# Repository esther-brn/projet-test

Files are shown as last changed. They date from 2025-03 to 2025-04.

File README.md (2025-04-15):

# 4GP 2024/2025 - Projet de capteur *low-tech en graphite* - Par Esther BOIRON et Margot HERNANDEZ
-------------------------

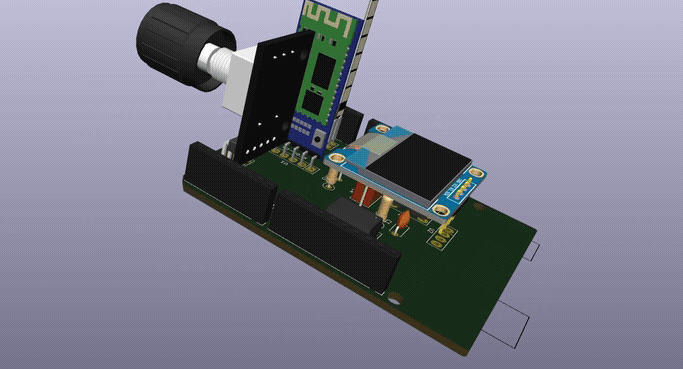
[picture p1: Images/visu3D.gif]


## Table des matières
* [Contacts](#contacts) 
* [Contexte](#contexte) 
* [Livrable](#livrable) 
* [Matériel requis](#matériel-requis) <br>
* [1. Simulation électronique sous LTSpice](#1-simulation-électronique-sous-ltspice) <br>
* [2. Design du PCB sous Kicad](#2-design-du-pcb-sous-kicad) <br>
* [3. Code sur Arduino](#3-code-sur-arduino) <br>
* [4. Application Android](#4-application-android) <br>
* [5. Réalisation du shield](#5-réalisation-du-shield) <br>
* [6. Banc de tests](#6-banc-de-tests) <br>
* [7. Résultats et discussion](#7-résultats-et-discussion) <br>
* [8. Datasheet du capteur](#8-datasheet-du-capteur) 
* [Conclusion](#conclusion)
------------
## Contacts
Esther BOIRON : eboiron@insa-toulouse.fr  
Margot HERNANDEZ : mhernan2@insa-toulouse.fr

------------
## Contexte
Dans le cadre de l’UF de quatrième année du département Génie Physique intitulée *Du capteur au banc de test*, nous avons développé et évalué la performance d’un capteur low-tech en graphite. Il est constitué d’un simple morceau de papier recouvert d’une trace de crayon à papier, formant une fine couche de graphite. Lorsque le papier se déforme, le nombre de particules de graphite reliées varie, entraînant une modification de la résistance du capteur. Ce phénomène permet ainsi de mesurer la déformation, à la manière d’une jauge de contrainte traditionnelle.

Ce travail s’appuie sur les recherches de scientifiques américains (Cheng-Wei Lin*, Zhibo Zhao*, Jaemyung Kim & Jiaxing Huang), qui ont publié en 2014 l’article [Pencil Drawn Strain Gauges and Chemiresistors on Paper](https://www.researchgate.net/publication/259846610_Pencil_Drawn_Strain_Gauges_and_Chemiresistors_on_Paper).

Vous trouverez ici l’ensemble des réalisations effectuées dans le cadre de ce projet : simulations électroniques, conception du PCB, programmation Arduino, développement d’une application Android et élaboration d’une datasheet.

------------
## Livrable
Plusieurs livrables sont attendus :

✓ Un shield PCB connecté à une carte Arduino UNO, intégrant : un capteur en graphite, un montage amplificateur transimpédance, un module Bluetooth, un écran OLED, un encodeur rotatif, un potentiomètre numérique ainsi qu'un capteur de flexion commercial (flex sensor).<br>

✓ Un code Arduino assurant le contrôle de l’ensemble des composants et la réalisation des mesures.<br>

✓ Une application Android permettant de visualiser les mesures depuis un smartphone.<br>

✓ Un code Arduino dédié aux essais du capteur sur le banc de test.<br>

✓ Une datasheet détaillant les caractéristiques du capteur en graphite.<br>

------------
## Matériel requis
Afin de réaliser notre dispositif, voici la liste des composants nécessaires :

Pour le montage amplificateur transimpédance :

* Des résistances : 1 de 1 kΩ, 1 de 10 kΩ, 2 de 100 kΩ
* Un potentiomètre numérique : ici, le MCP41050
* Des condensateurs : trois de 100 nF et un de 1 μF
* Un amplificateur opérationnel : ici, le LTC1050

Pour le reste du dispositif :
* Un module Bluetooth : ici, le HC05
* Un écran OLED : ici, un écran de dimensions 128x64
* Un encodeur rotatif
* Un capteur de flexion (flex sensor)
* Une résistance de 33 kΩ
* Une carte Arduino UNO
------------
## 1. Simulation électronique sous LTSpice
Notre objectif est de mesurer la résistance de notre capteur en graphite puis de retrouver sa déformation par une relation de proportionalité. Nous savons que la résistance est de l’ordre du gigaohm (GΩ). Sous une tension de 5V, correspondant à celle délivrée par l’Arduino, le capteur délivre un courant extrêmement faible, de l’ordre de quelques nanoampères (nA). Cette mesure ne peut donc pas se faire directement : nous devons amplifier le signal. De plus, nous utilisons l'Arduino Uno et ce microcontrôleur ne peut mesurer que des tensions (cf [datasheet](https://docs.arduino.cc/resources/datasheets/A000066-datasheet.pdf)). Nous avons donc besoin d'un montage amplificateur transimpédance pour convertir notre courant en une tension exploitable par les entrées analogiques de l'Arduino. Pour cela, nous avons choisi l’amplificateur opérationnel  LTC1050.

Associé à cet amplificateur, nous réalisons un montage structuré en trois zones principales qui correspondent à des filtres pour améliorer la qualité du signal mesuré :

* Filtrage en entrée de l'amplificateur (R1 et C1) : un filtre passe-bas passif de fréquence de coupure de 16 Hz qui permet de filtrer le bruit en courant sur le signal d'entrée
* Filtrage couplé à l'amplificateur (R3 et C4) : un filtre passe-bas actif de fréquence de coupure de 1.6 Hz qui permet de filtrer la composante 50 Hz issue du réseau électrique 
* Filtrage à la sortie de l'amplificateur (R6 et C2) : filtre passe bas passif de fréquence de coupure de 1.6 kHz qui permet de réduire le bruit créé lors du traitement du signal (bruits des alimentations, de l’horloge…)

<p align="center">
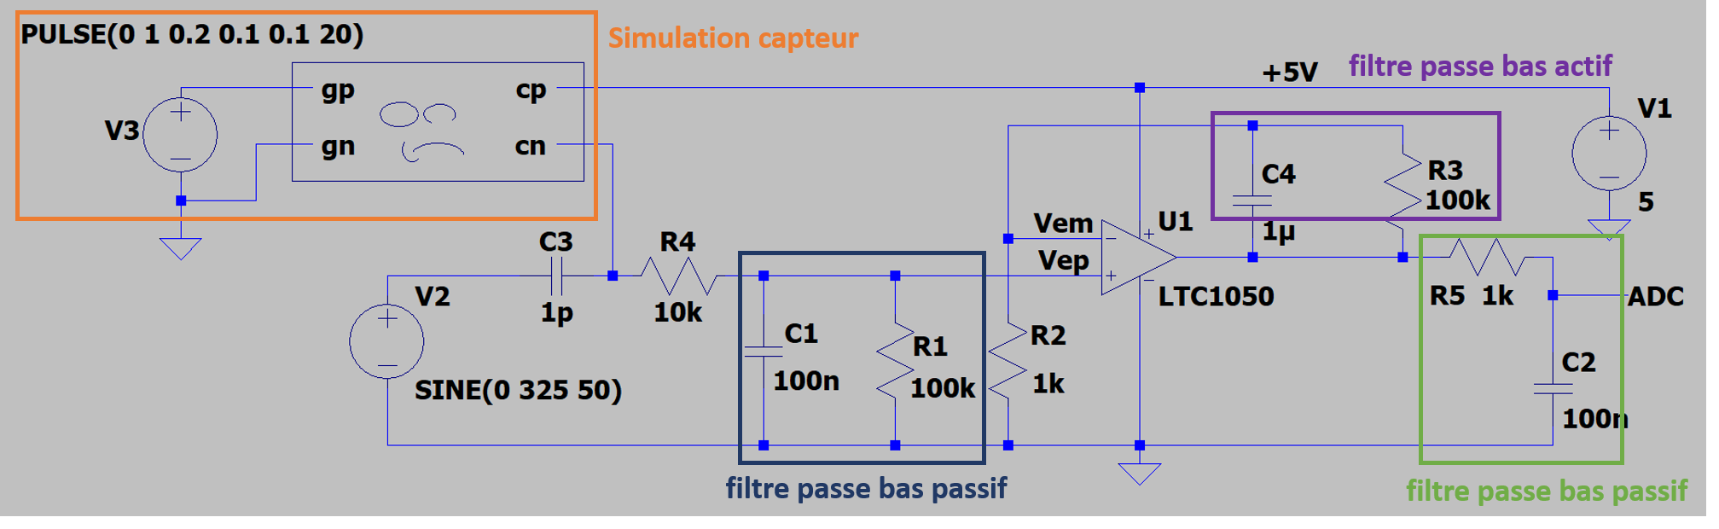
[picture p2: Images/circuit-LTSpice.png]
Image circuit LTSpice
  
</p>

Afin de pouvoir ajuster dynamiquement le gain de l’amplificateur en fonction des besoins de mesure, la résistance R2 sera remplacée ultérieurement par un potentiomètre digital.

Nous avons validé notre montage sur LTSpice en deux étapes :

Tout d'abord, nous avons réalisé une première simulation afin de s’assurer que l’amplification fonctionne correctement. L’image ci-dessous montre que le signal est bien amplifié à 1 V : le signal a donc une valeur suffisante pour être interprété par l’Arduino.

<p align="center">
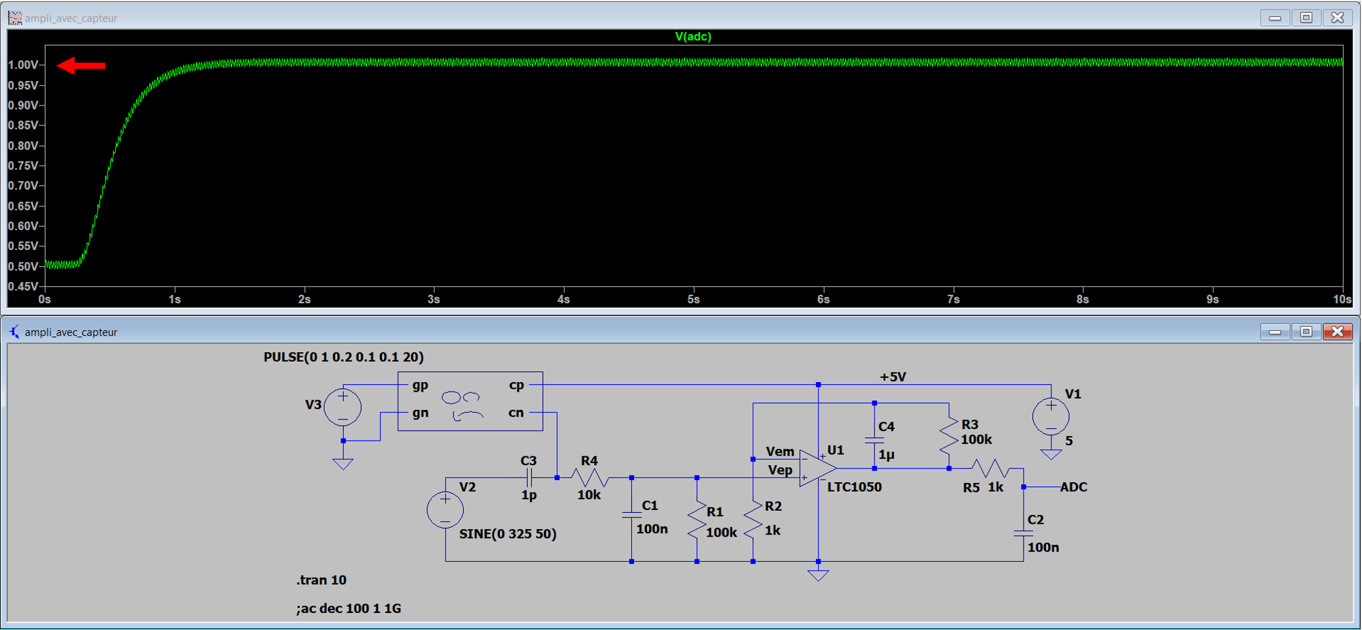
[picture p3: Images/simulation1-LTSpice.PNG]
Image circuit LTSpice
  
</p>

Ensuite, nous avons réalisé une seconde simulation afin d'observer la réponse à un courant alternatif afin de vérifier l’efficacité du filtrage. Les variations de la phase observées sur le graphe ci-dessous illustrent le passage du signal à travers les trois filtres successifs.
<p align="center">
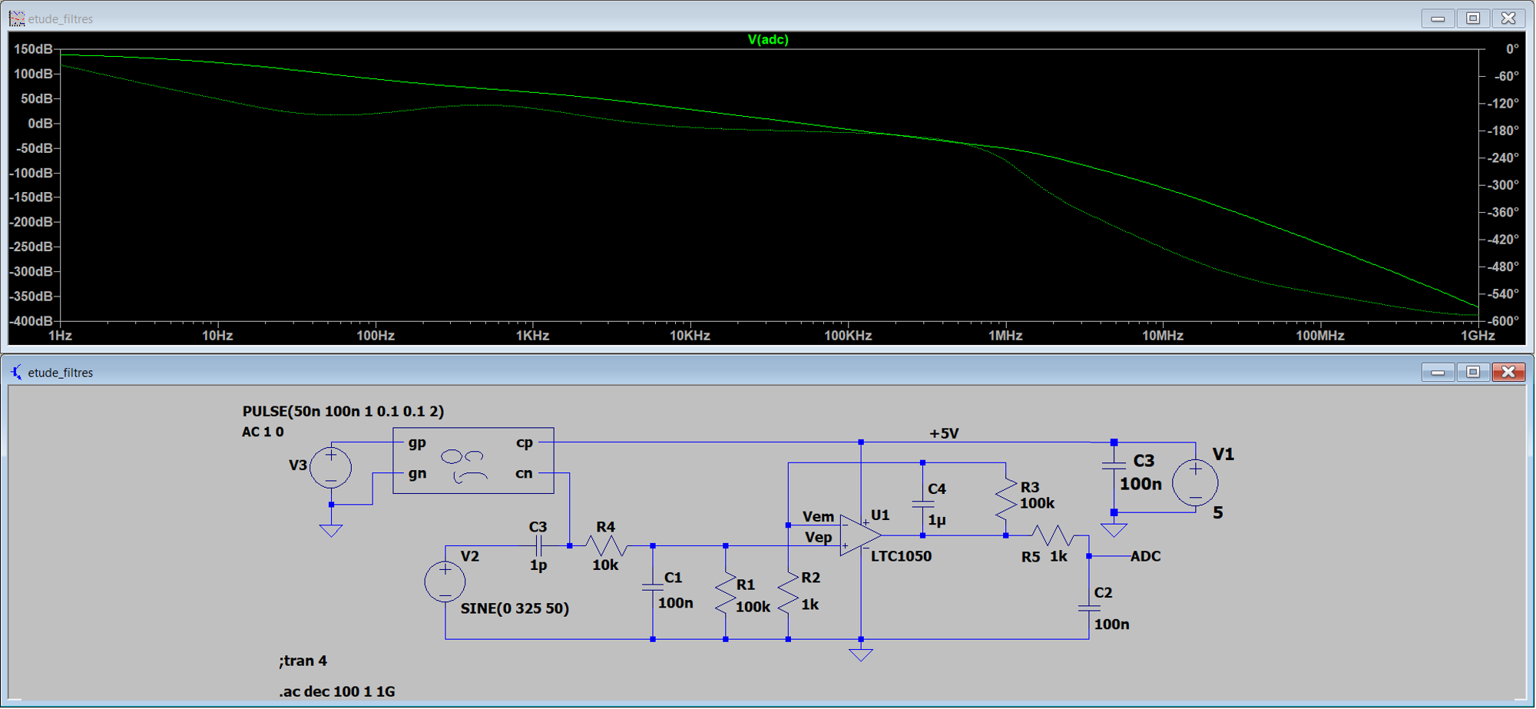
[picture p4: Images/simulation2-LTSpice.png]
Image circuit LTSpice
  
</p>

------------
## 2. Design du PCB sous Kicad
Après avoir réalisé les simulations sur LTSpice, nous avons conçu notre PCB à l’aide du logiciel KiCad. Pour cela, nous sommes parties du schéma du montage décrit précédemment, auquel nous avons apporté quelques modifications.
Parmi ces modifications, nous avons notamment remplacé la résistance R2 par un potentiomètre numérique permettant un réglage précis du gain de l’amplificateur, tout en évitant la saturation. Nous avons également ajouté plusieurs composants afin d’améliorer les fonctionnalités de notre système et de comparer les résultats obtenus :
* Le module Bluetooth HC-05 : permet d'assurer la communication entre le PCB et un smartphone via une application Android.
* Un écran OLED : utilisé pour afficher différents menus en temps réel.
* Un encodeur rotatif : contrôle la navigation entre les différentes options affichées sur l’écran OLED.
* Un flex sensor : utilisé pour comparer les mesures du capteur en graphite avec celles d’un capteur commercial lors des tests finaux

__Création des bibliothèques et symboles__  

La première étape de la conception a consisté à créer notre propre bibliothèque de symboles pour les composants spécifiques du montage. Nous avons dessiné les symboles correspondants aux différents composants utilisés. L’image ci-dessous illustre, par exemple, le symbole de l’écran OLED.

<p align="center">
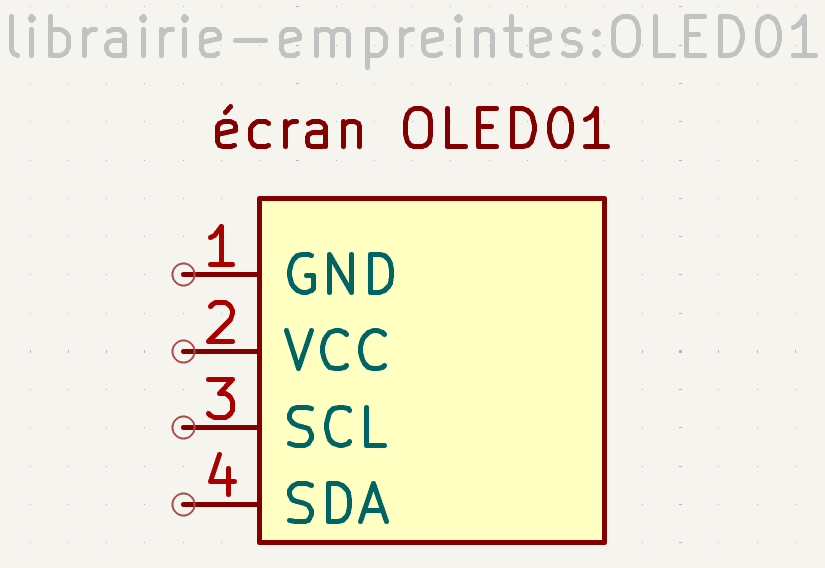
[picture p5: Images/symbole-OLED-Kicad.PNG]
Image circuit LTSpice
  
</p>

__Création des empreintes des composants__

La deuxième étape a consisté à créer les empreintes des composants. Cette phase est essentielle pour garantir une bonne intégration des composants sur le circuit imprimé. Pour cela, nous avons pris en compte la dimension physique des composants ainsi que le diamètre des trous. L’image ci-dessous illustre l’empreinte de l’écran OLED.

<p align="center">
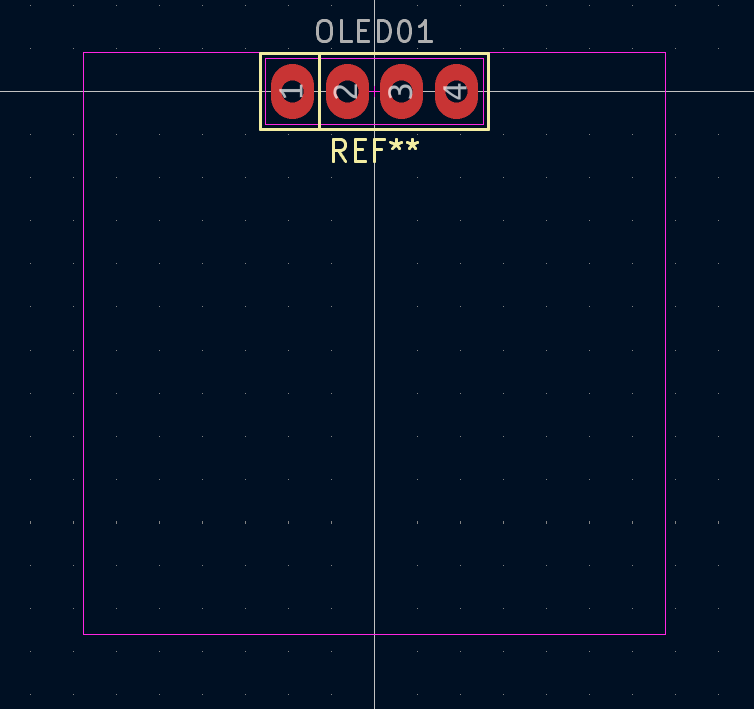
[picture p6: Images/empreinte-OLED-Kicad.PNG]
Image circuit LTSpice
  
</p>

Afin d’obtenir une visualisation 3D réaliste de notre PCB final, nous avons associé à chaque empreinte une modélisation 3D du composant correspondant. Cette étape permet de vérifier l’agencement des composants, d’anticiper d’éventuels problèmes d’encombrement et d’optimiser le design du circuit imprimé.
Les modèles 3D utilisés ont été récupérés sur la plateforme GrabCAD, qui propose une large bibliothèque de fichiers compatibles avec KiCad.
L’image ci-dessous illustre la modélisation 3D de l’écran OLED.

<p align="center">
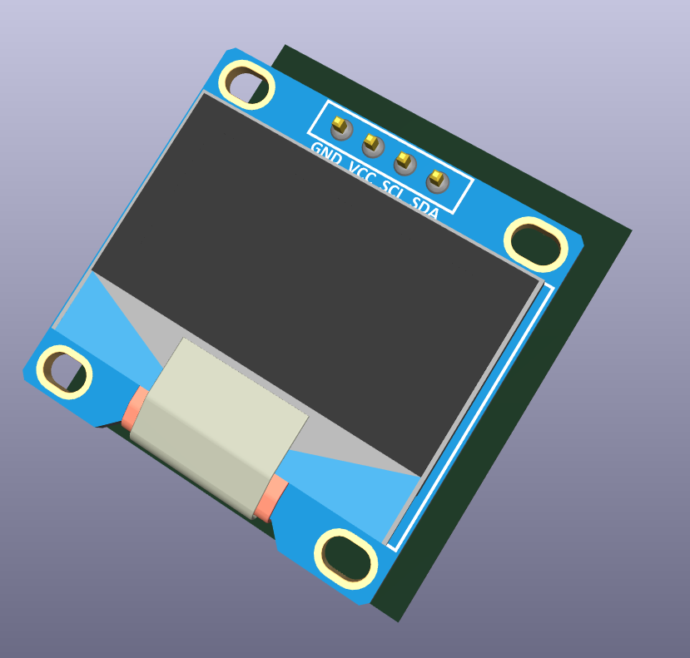
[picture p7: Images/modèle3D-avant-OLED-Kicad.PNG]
Image circuit LTSpice
  
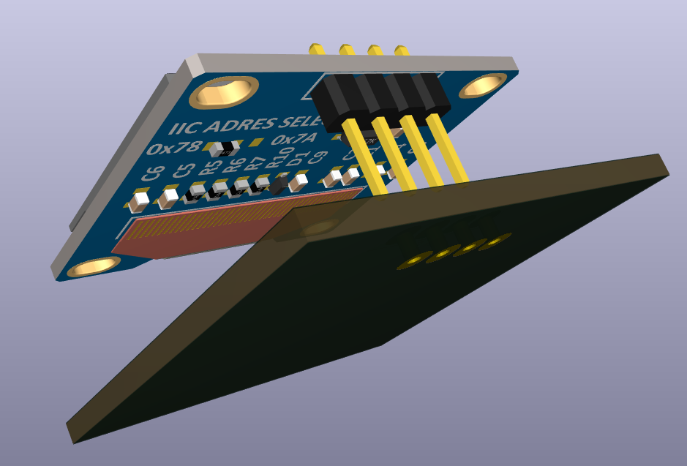
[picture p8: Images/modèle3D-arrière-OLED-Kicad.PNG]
Image circuit LTSpice
  
</p>

__Création de la schématique électrique__

Après avoir défini les empreintes et les modèles 3D des composants, nous avons procédé à la création de la schématique électrique du montage. Lors de cette étape, nous avons opté pour un modèle basé sur l’Arduino UNO afin de garantir la correspondance correcte des pins de connexion avec l’Arduino.

<p align="center">
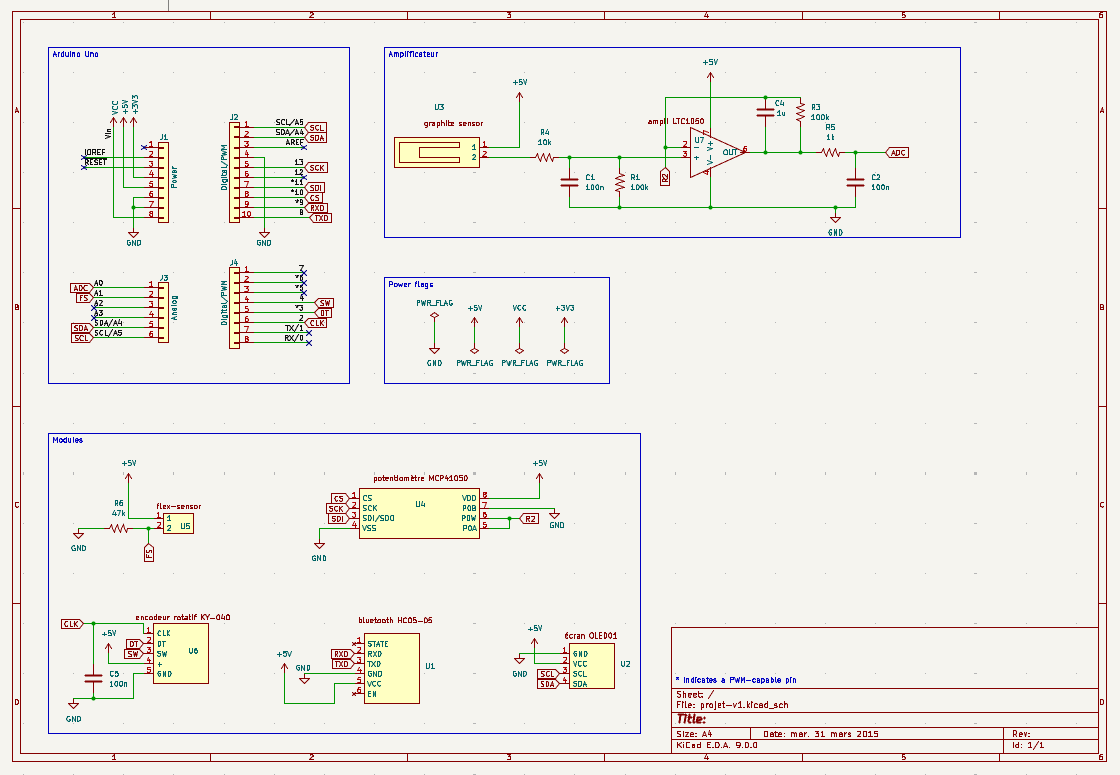
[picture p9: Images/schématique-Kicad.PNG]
Image circuit LTSpice
  
</p>

__Disposition des composants sur le PCB__

La dernière étape de notre conception a été l’agencement des composants sur le PCB. L’objectif principal est d’optimiser leur disposition en tenant compte des connexions électriques tout en minimisant l’utilisation de vias. Les images ci-dessous présentent le résultat final de notre PCB, ainsi que sa vue en 3D, permettant de visualiser l’implantation des composants.

<p align="center">
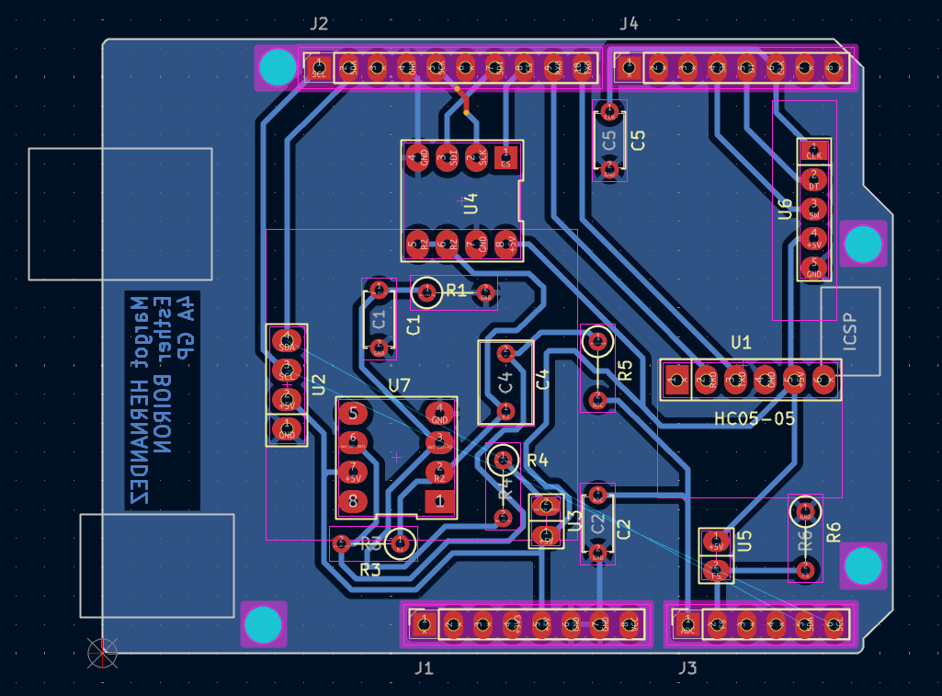
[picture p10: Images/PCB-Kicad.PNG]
Image circuit LTSpice
  
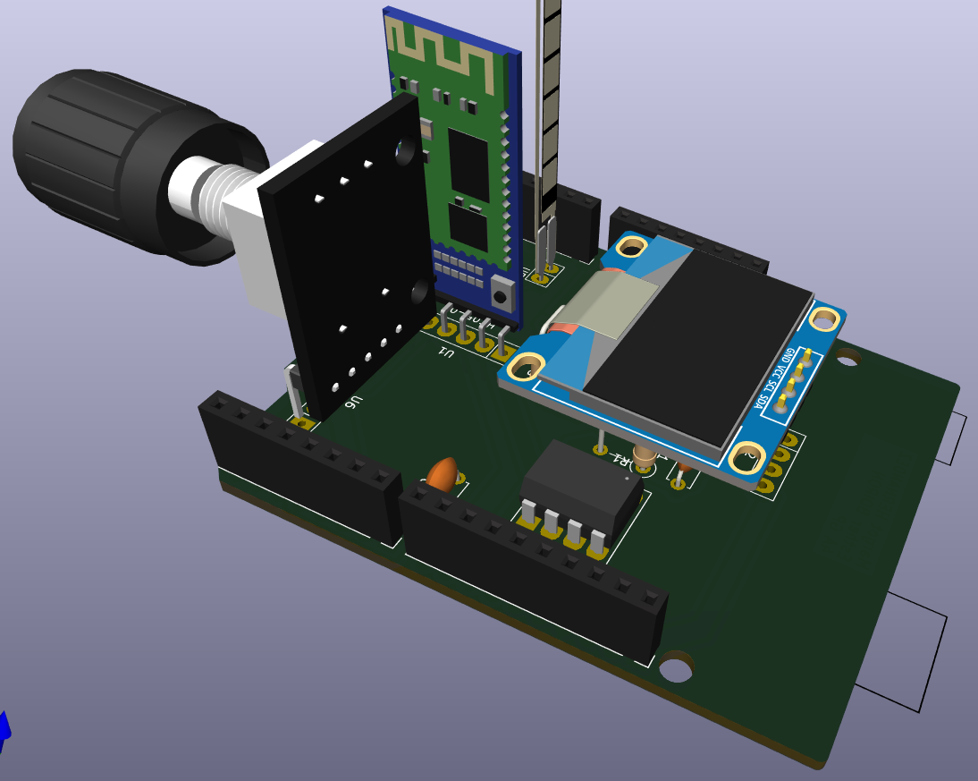
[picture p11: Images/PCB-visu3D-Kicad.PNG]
Image circuit LTSpice
  
</p>

------------
## 3. Code sur Arduino
Notre code Arduino, conçu pour contrôler les composants implémentés et effectuer les mesures à l’aide du capteur en graphite et du capteur commercial, a été développé sous [Arduino IDE 2.3.4](https://www.arduino.cc/en/software/).  

Nous avons utilisé les bibliothèques *SoftwareSerial.h* pour la communication Bluetooth et *Adafruit_SSD1306.h* pour l'affichage sur écran OLED. Étant donné que notre programme utilise une part importante de la mémoire RAM, nous avons rencontré des problèmes de stockage : le programme ne se lançait pas et aucune information n'était affichée dans l'IDE lors du téléversement. Pour remédier à cela, nous avons intégré la bibliothèque *avr/pgmspace.h*, qui permet de stocker des données en mémoire flash afin de libérer de l’espace dans la RAM. 

Nous avons réalise un premier programme qui permet de calibrer le potentiomètre digitale afin d’optimiser les mesures réalisées par les deux capteurs. Le programme principal propose une interface à l’écran avec quatre menus, accessibles en tournant l’encodeur rotatif. La sélection d’un menu se fait en appuyant sur le bouton intégré à l’encodeur. Ce bouton permet également de revenir au menu principal lorsque nous sommes dans un sous-menu.  

Les sous-menus disponibles sont les suivants :
* Menu Informations : fournit des détails sur le projet.
* Menu Application : permet d'établir une communication avec l’application Android via le module Bluetooth.
* Menu Capteur Graphite : affiche en temps réel la valeur de résistance mesurée par le capteur en graphite.
* Menu Capteur Commercial : affiche en temps réel la valeur de résistance mesurée par le capteur commercial.<br>

Les codes complets sont disponibles dans le dossier [Arduino](Arduino).

Ci-dessous, une vidéo illustrant les différents menus accessibles sur l’écran OLED :



------------
## 4. Application Android
Nous avons également réalisé une application Android développée sous [MIT App Inventor](https://appinventor.mit.edu/).

<p align="center">
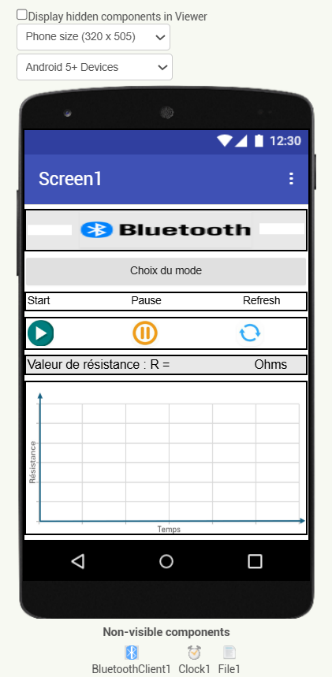
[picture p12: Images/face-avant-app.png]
Face avant application
  
</p>

Cette application reçoit les données transmises par le module Bluetooth HC-05 lorsque l’utilisateur est dans le mode « application » de l’écran OLED accessible via l’encodeur rotatif. 

Deux modes sont disponibles à partir d’un listpicker : le mode « capteur graphite » et le mode « capteur commercial ». Dans chacun de ces modes, la valeur de la résistance du capteur est affichée en temps réel. En cliquant sur le bouton « start », l’application passe en mode acquisition et trace l’évolution de la résistance sur un graphique en fonction du temps. L’acquisition est arrêtée en cliquant sur « pause ». Le bouton refresh permet de réinitialiser le graphique en effaçant les données précédemment tracées.

L’application ainsi que son code source sont disponibles dans le répertoire [Application](Application).

------------
## 5. Réalisation du shield
Après la conception et la validation du PCB, nous avons procédé à la fabrication physique du shield en suivant plusieurs étapes :
* Vérification du PCB sur KiCad : utilisation de l’outil Contrôle des règles de conception (DRC) pour s’assurer qu’il n’y a pas d’erreur dans les connexions et les espacements des pistes.
* Impression du masque de gravure sur un papier transparent 
* Insolation UV d’une plaquette d’époxy recouverte d’une couche de cuivre et de résine photosensible : la plaquette est exposée aux UV à travers le masque
* Révélation du motif : la plaquette est immergée dans un révélateur (soude très diluée) afin d'éliminer la résine exposée aux UV et laisser les pistes de cuivre protégées 
* Gravure des pistes : la plaquette est immergée dans un bain de perchlorure de fer pour graver les pistes
* Nettoyage de la plaquette : utilisation d'acétone pour retirer les résidus de résine 
* Perçage des trous et soudure des composants sur le PCB

<p align="center">
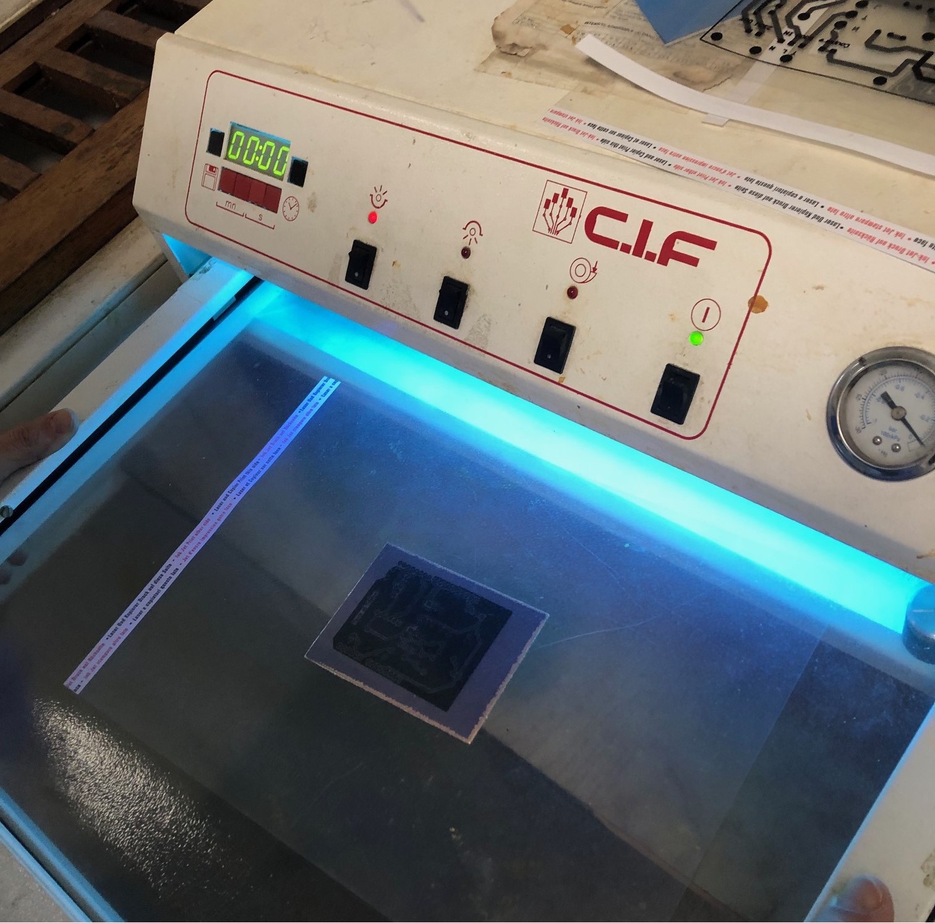
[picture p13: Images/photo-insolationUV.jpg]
Image photo insolation UV
  
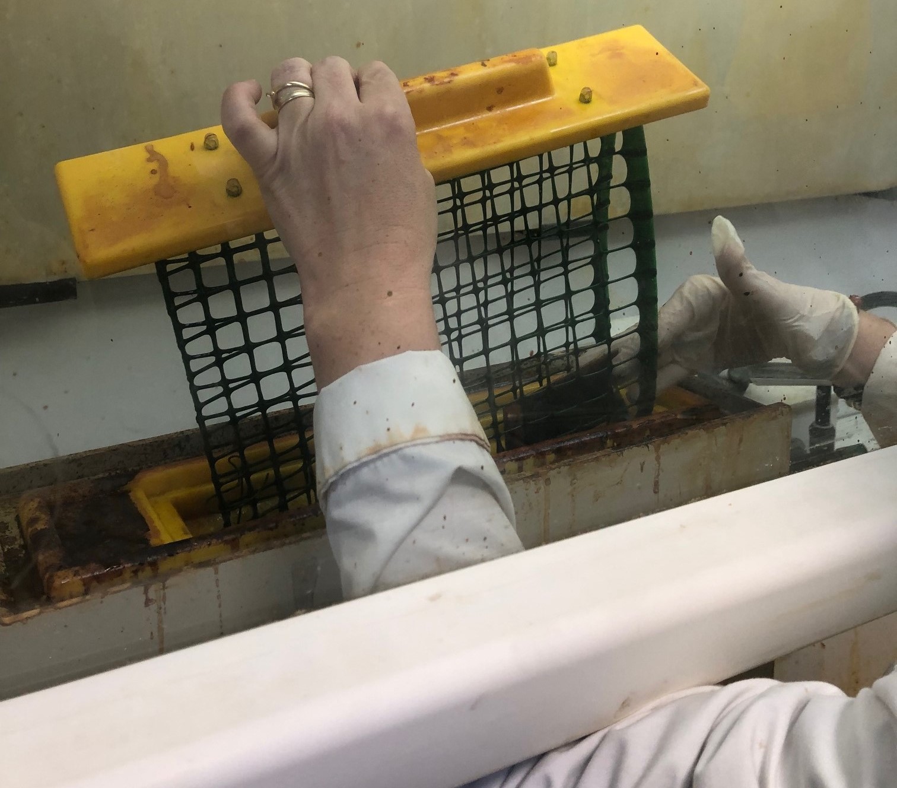
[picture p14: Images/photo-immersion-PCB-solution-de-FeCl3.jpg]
Image imersion PCB
  
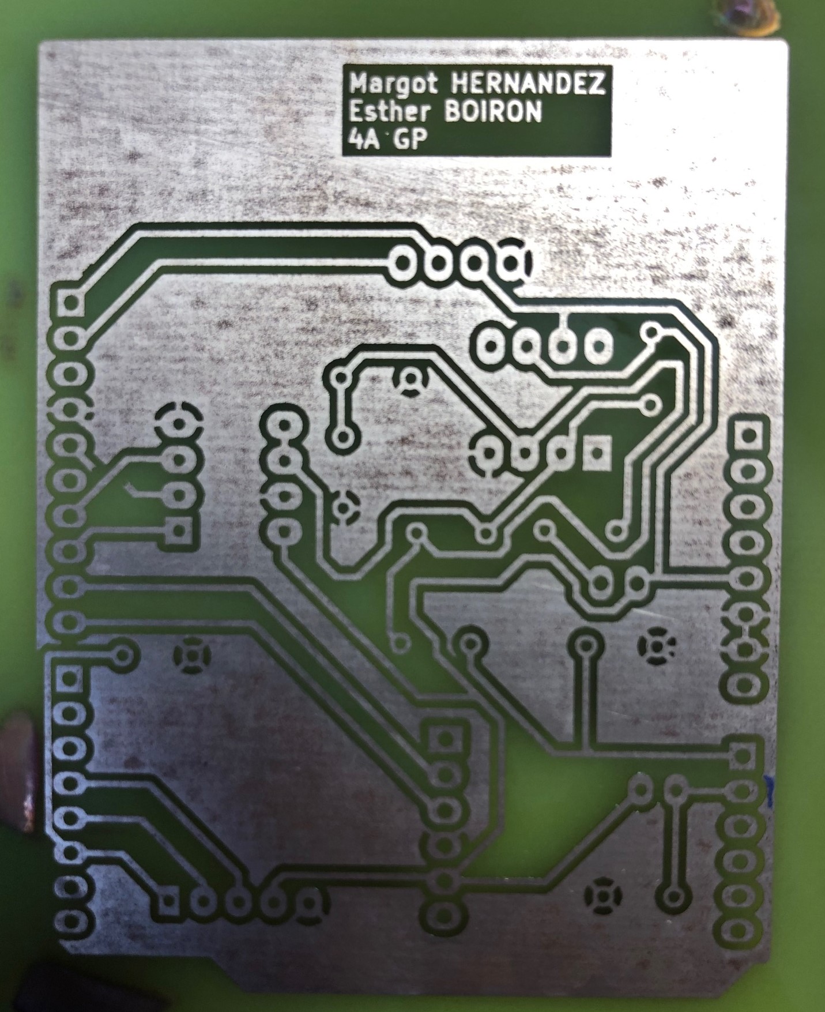
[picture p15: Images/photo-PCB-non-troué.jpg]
Image PCB non troué
  
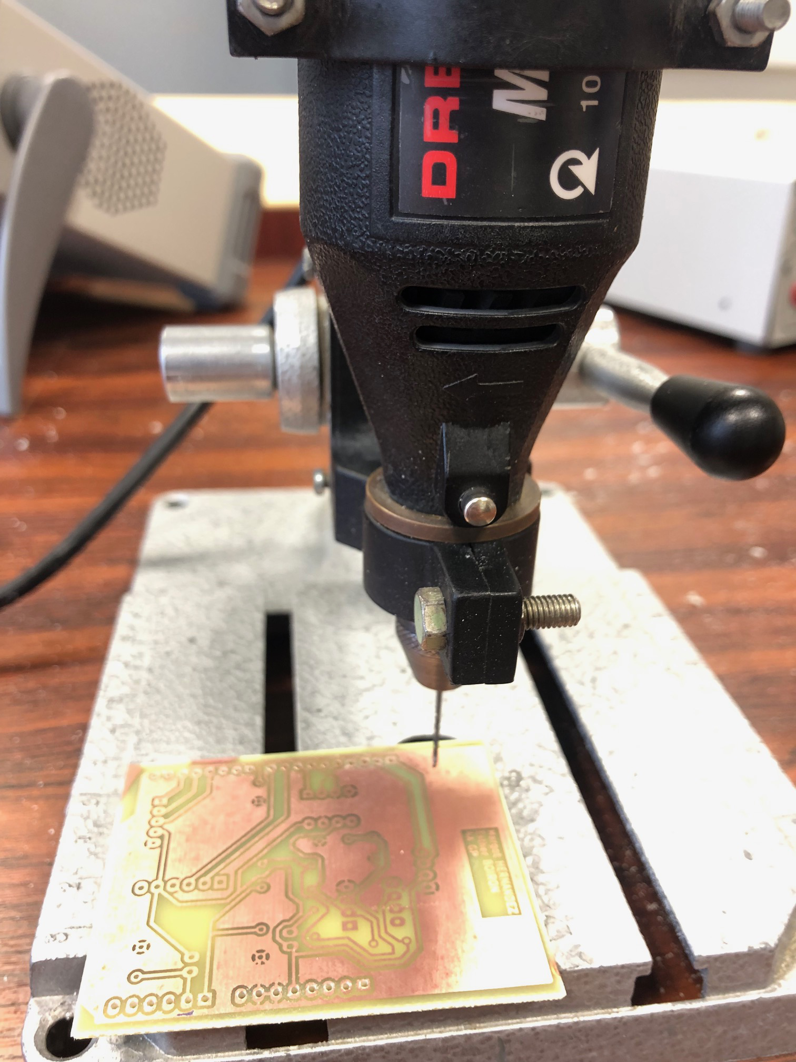
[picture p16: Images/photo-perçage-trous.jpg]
Image perçage trous
  
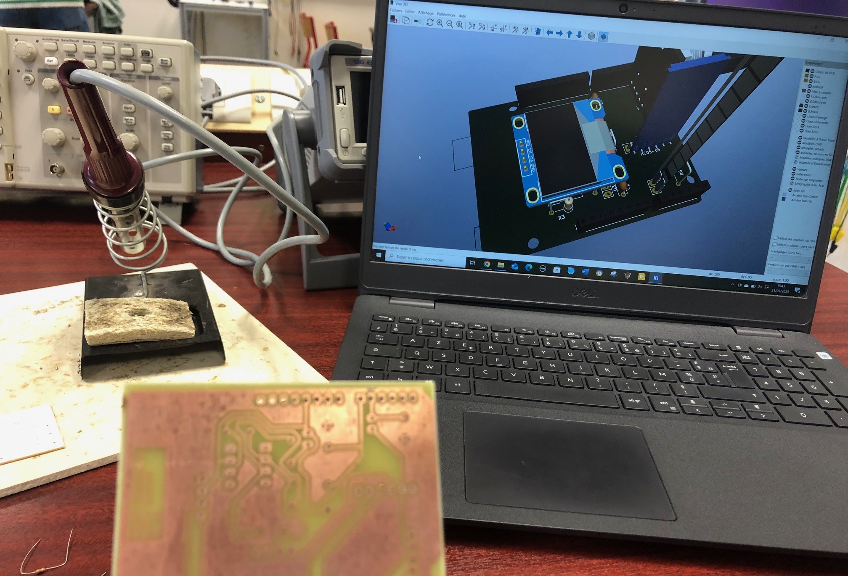
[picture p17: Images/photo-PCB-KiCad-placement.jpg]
Image PCB cablâge
  
</p>

------------
## 6. Banc de tests
Le but de ce banc de test est de déterminer la sensibilité du capteur, d’étudier son évolution, puis de la comparer à celle d’un capteur commercial de type "Flex-Sensor". Pour cela, nous avons utilisé le banc de test suivant, composé de six cercles dont les diamètres varient de 1.4 à 3.9 cm. Ce banc a été fabriqué à l’aide d’une imprimante 3D.

<p align="center">
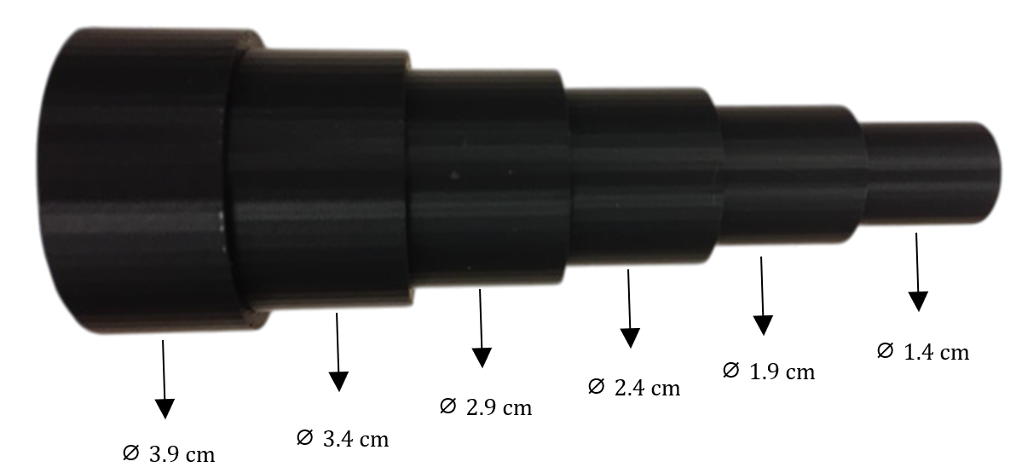
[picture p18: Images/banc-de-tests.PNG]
Banc de tests
  
</p>

Ce banc de test permet de mesurer la variation de résistance relative ΔR/R0 en fonction de la déformation ε, définie par la relation ε =e/D où e est l'épaisseur du capteur (ici celle de la feuille, soit 0,2 mm) et D le diamètre du cercle considéré.  

Les tests ont été réalisés en tension et en compression sur des capteurs à base de graphite.

<p align="center">
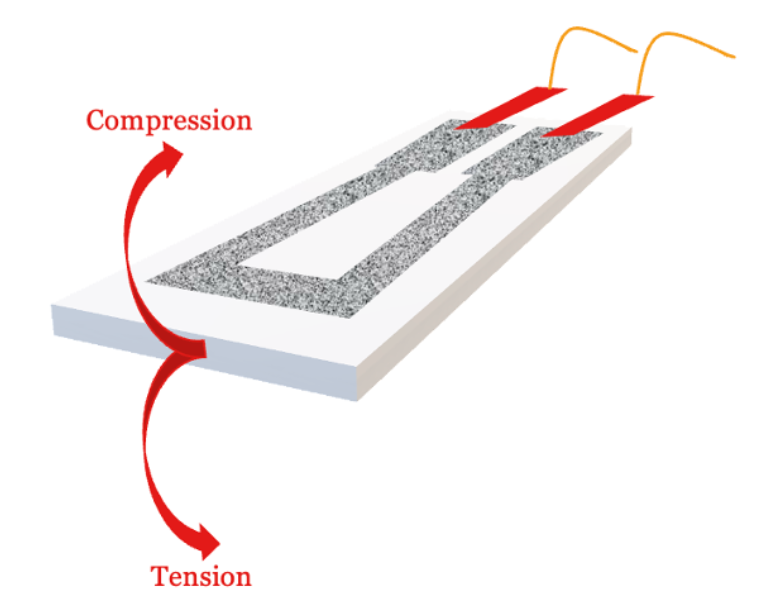
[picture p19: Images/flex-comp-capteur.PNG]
Schéma compression et tension
  
</p>

Ces capteurs ont été fabriqués à l’aide de quatre types de graphite différents : des crayons 6B, 4B, B et HB. Pour maintenir les capteurs en papier sur le banc de test sans les toucher pendant les mesures, nous avons utilisé de la pâte à fixe.

<p align="center">
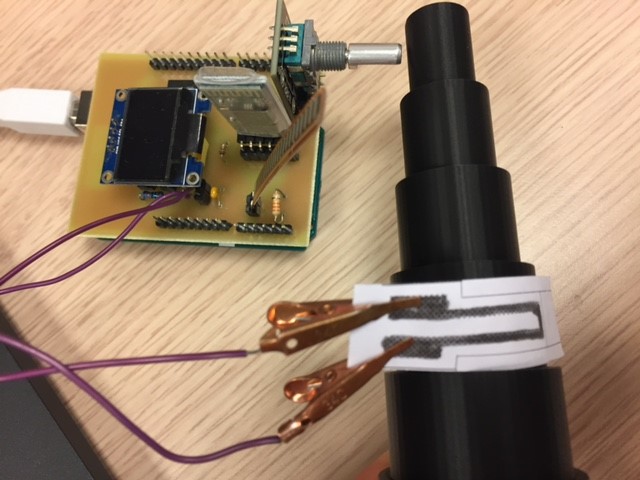
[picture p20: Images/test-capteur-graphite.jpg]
Test capteur graphite
  
</p>

------------
## 7. Résultats et discussion
Les courbes ci-dessous illustrent les variations de la résistance en fonction de la déformation, en tension et en compression, pour des capteurs en graphite réalisés avec différents types de crayons. 

<p align="center">
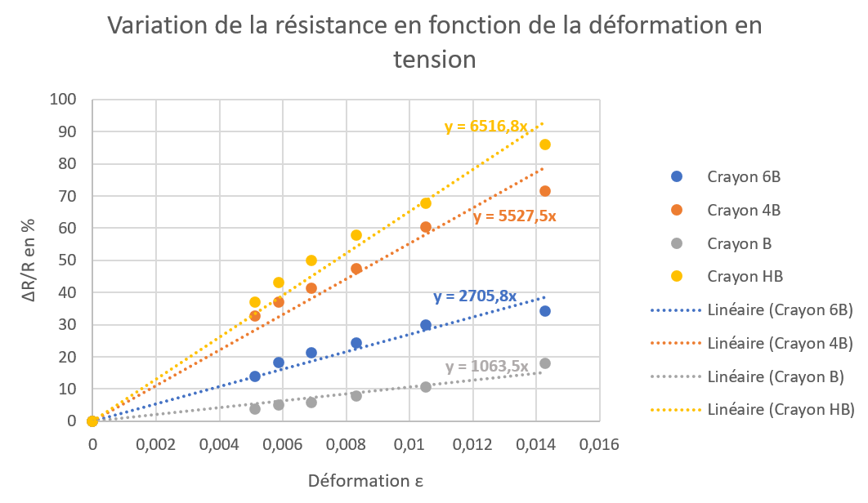
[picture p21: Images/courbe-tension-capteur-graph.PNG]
Courbe de déformation en tension capteur graphite
  
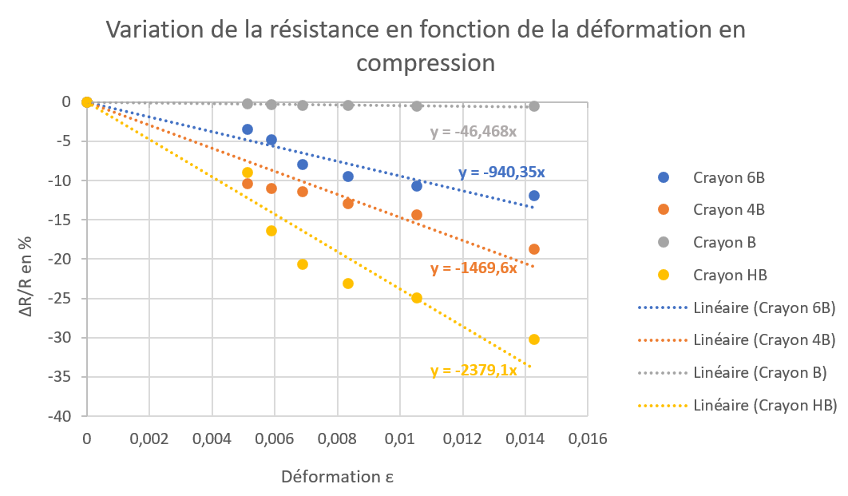
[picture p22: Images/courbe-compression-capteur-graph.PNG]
Courbe de déformation en compression capteur graphite
  
</p>

La courbe ci-dessous présente le comportement du capteur commercial pour une déformation en tension, le flex sensor ne supportant pas une déformation en compression. 

<p align="center">
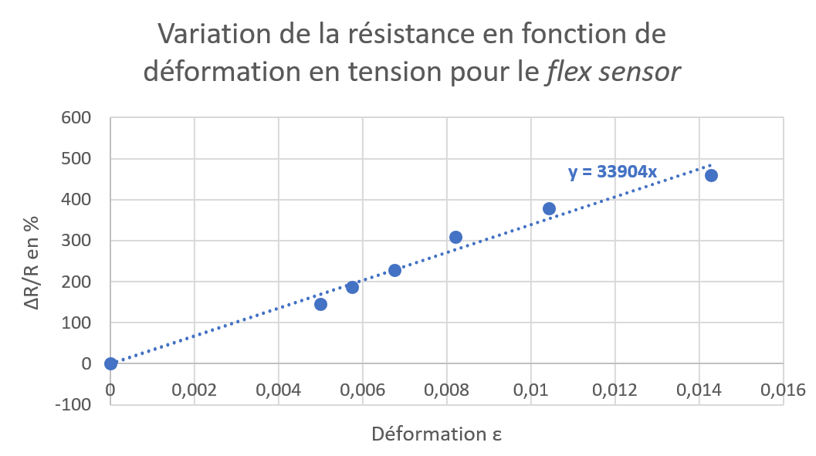
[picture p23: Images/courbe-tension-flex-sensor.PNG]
Courbe de déformation en tension flex sensor
  
</p>

On remarque que lorsque le capteur graphite est soumis à une déformation en tension, la résistance du capteur augmente. Ce phénomène est attendu : en tension, les distances entre les nanoparticules de graphite s’allongent, ce qui freine le passage du courant et augmente la résistance. A l’inverse, lors d’une compression, les grains se rapprochent, facilitant le passage du courant et donc la résistance diminue.  

Les résultats montrent aussi que le type de crayon utilisé influence fortement les valeurs de résistance mesurées. Plus un crayon est gras (comme le 6B ou le 4B), plus il dépose de graphite sur le papier, ce qui réduit la résistance globale du capteur. Les courbes indiquent également que plus un crayon est gras, moins la variation relative de la résistance est importante. Autrement dit, les capteurs réalisés avec des crayons plus gras sont moins sensibles à la déformation.  

Ces résultats expérimentaux permettent de conclure que le capteur commercial est globalement plus sensible à la déformation que les capteurs en graphite. De plus, il présente une bien meilleure robustesse : les capteurs en graphite sont fragiles et le simple fait de toucher leur surface peut altérer le dépôt de graphite, faussant les mesures qui suivent. Il faut les manipuler avec beaucoup de précaution. Leur durée de vie est aussi limitée, en particulier lorsqu’ils sont soumis à de fortes déformations. Entre chaque série de tests (tension ou compression), il a été nécessaire de fabriquer un nouveau capteur, car la résistance au repos changeait significativement après les premières déformations.  

Il est important de noter que plusieurs facteurs peuvent influencer les résultats, notamment la quantité de graphite déposée sur le papier, qui est difficile à maîtriser précisément. Cette variabilité peut entraîner des écarts non négligeables dans les mesures. Une amélioration possible consisterait à développer un procédé de dépôt de graphite d’une quantité fixe et reproductible, ainsi qu’un système de protection de la face du capteur contenant le trait de graphite pour éviter la perte de matière au contact.  

Le capteur commercial s'avère donc plus précis, plus robuste, et mieux adapté à des mesures répétées ou à des déformations importantes. En revanche, les capteurs en graphite présentent l’avantage de pouvoir mesurer des déformations en compression, contrairement au flex-sensor.

------------
## 8. Datasheet du capteur
Vous pouvez trouver la datasheet du capteur [ici](Datasheet.pdf).

------------
## Conclusion
Ce projet a été très enrichissant, nous offrant une immersion concrète dans le métier d’ingénieur, avec des tâches variées allant des phases de simulation jusqu’à la rédaction d’une datasheet. Nous avons apprécié la diversité des compétences mobilisées : conception électronique, fabrication, expérimentation et analyse, ainsi que la satisfaction de voir aboutir un produit final fonctionnel.  

Le capteur que nous avons développé est opérationnel et les tests réalisés mettent en évidence des tendances globalement cohérentes avec les principes physiques attendus. Ces résultats montrent qu’un simple matériau comme le graphite peut être exploité pour détecter des déformations mécaniques.  

Cependant, les conditions expérimentales mises en œuvre restent assez artisanales et peu reproductibles. La précision des mesures est fortement influencée par des paramètres difficilement maîtrisables, tels que la quantité de graphite déposée ou la qualité du contact des pinces sur les traits de crayon du capteur. De plus, la fragilité du capteur et sa très faible durée de vie rendent son industrialisation peu envisageable.

<br><br><br><br><br>

<p align="center">
  Fin de page
</p>

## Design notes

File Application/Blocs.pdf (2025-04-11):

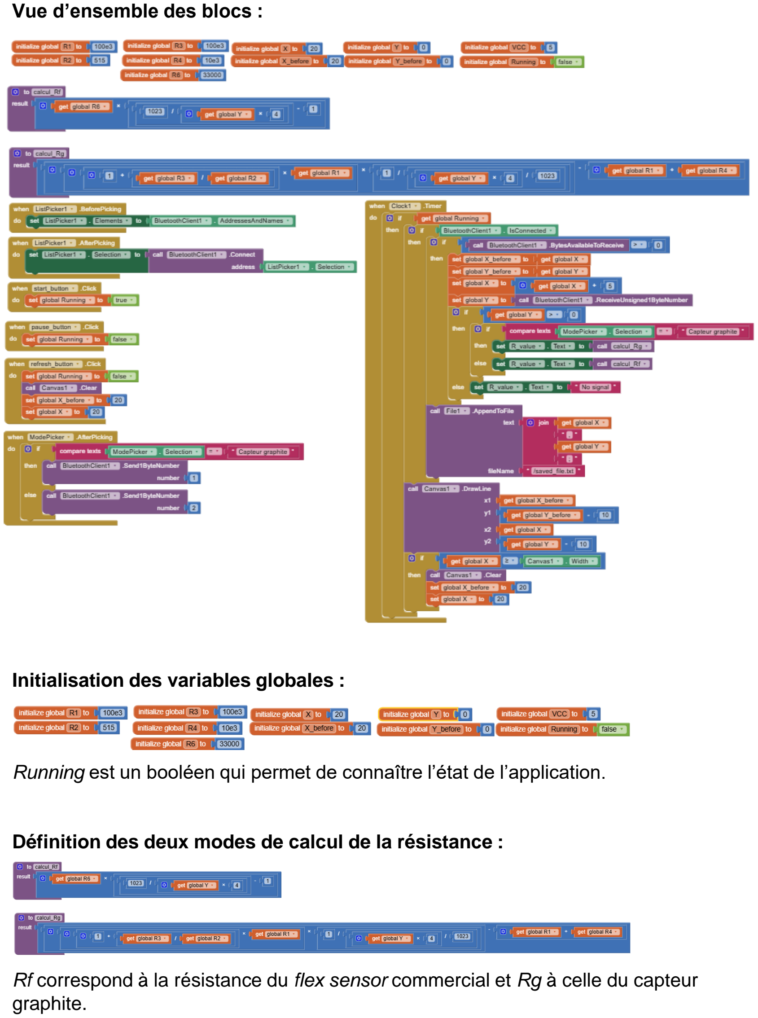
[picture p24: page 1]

Vue d’ensemble des blocs :

Initialisation des variables globales :

Running est un booléen qui permet de connaître l’état de l’application.

Définition des deux modes de calcul de la résistance :

Rf correspond à la résistance du flex sensor commercial et Rg à celle du capteur graphite.

Gestion du client Bluetooth :

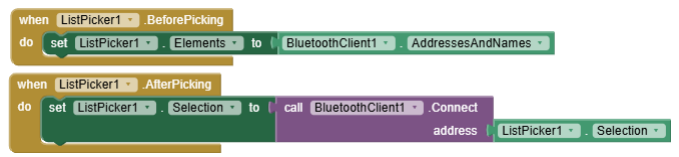
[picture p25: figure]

Le premier bloc définit les éléments du listpicker avec les noms des appareils Bluetooth qui on déjà été appairés au téléphone auparavant. Le second bloc connecte le téléphone à l’appareil sélectionné par l’utilisateur.

Définition des évènements associés à chaque bouton :

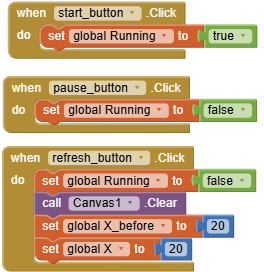
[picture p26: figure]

Définition des modes de l’application :

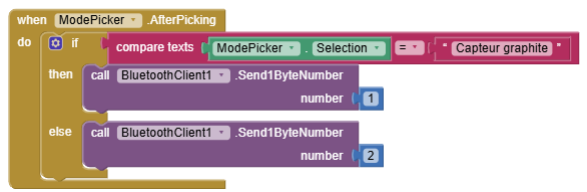
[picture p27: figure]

L’utilisateur peut choisir entre le mode capteur graphite et le mode capteur commercial via un listpicker. Selon le mode sélectionné, le module Bluetooth envoie la valeur 1 ou 2 à la carte Arduino. Dans le code Arduino, lorsqu’on est dans le menu Application, on lit le mode demandé (1 → graphite, 2 → commercial) et en fonction, on envoie la valeur de tension associée au capteur graphite ou au capteur commercial.

•Quand on clique sur start, la variable global Running passe à vrai donc l’application est en mode running. On utilisera cette information pour faire tourner la boucle principale.

•Quand on clique sur pause, on suspend l’exécution de la boucle principale.

•Quand on clique sur refresh, on suspend l’exécution de la boucle principale et on réinitialise le graphique.

Boucle principale :

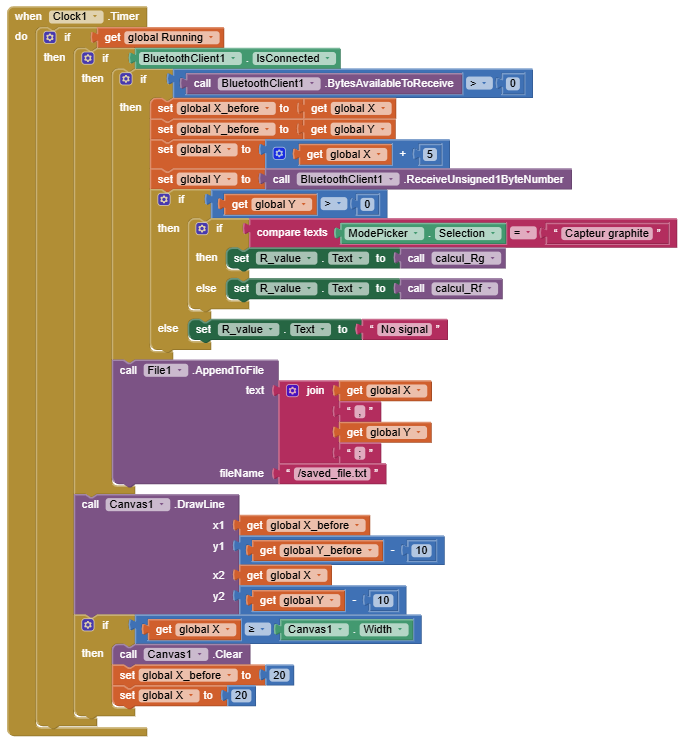
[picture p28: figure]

Pour séquencer le programme, on utilise un timer. Toutes les 100 ms, on regarde si l’application est en mode Running : si ce n’est pas le cas, on ne fait rien. A l’inverse, si on est en mode Running, on vérifie la connexion au module Bluetooth, on lit la valeur de tension qu’il nous envoie et on met à jour nos variables globales. Selon le mode choisi par l’utilisateur, on utilise la fonction adaptée pour le calcul de résistance. Cette valeur de résistance est affichée sur l’écran puis les coordonnées (x,y) sont sauvegardées dans un fichier. Enfin, on trace sur le graphique une ligne entre les coordonnées précédentes et les nouvelles. Si on est hors intervalle, on rafraîchit le graphique et on réinitialise x.

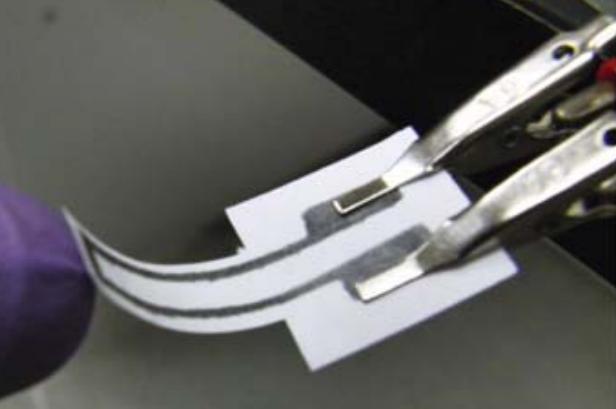
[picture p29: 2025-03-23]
Images/image-capteur-graphite.png

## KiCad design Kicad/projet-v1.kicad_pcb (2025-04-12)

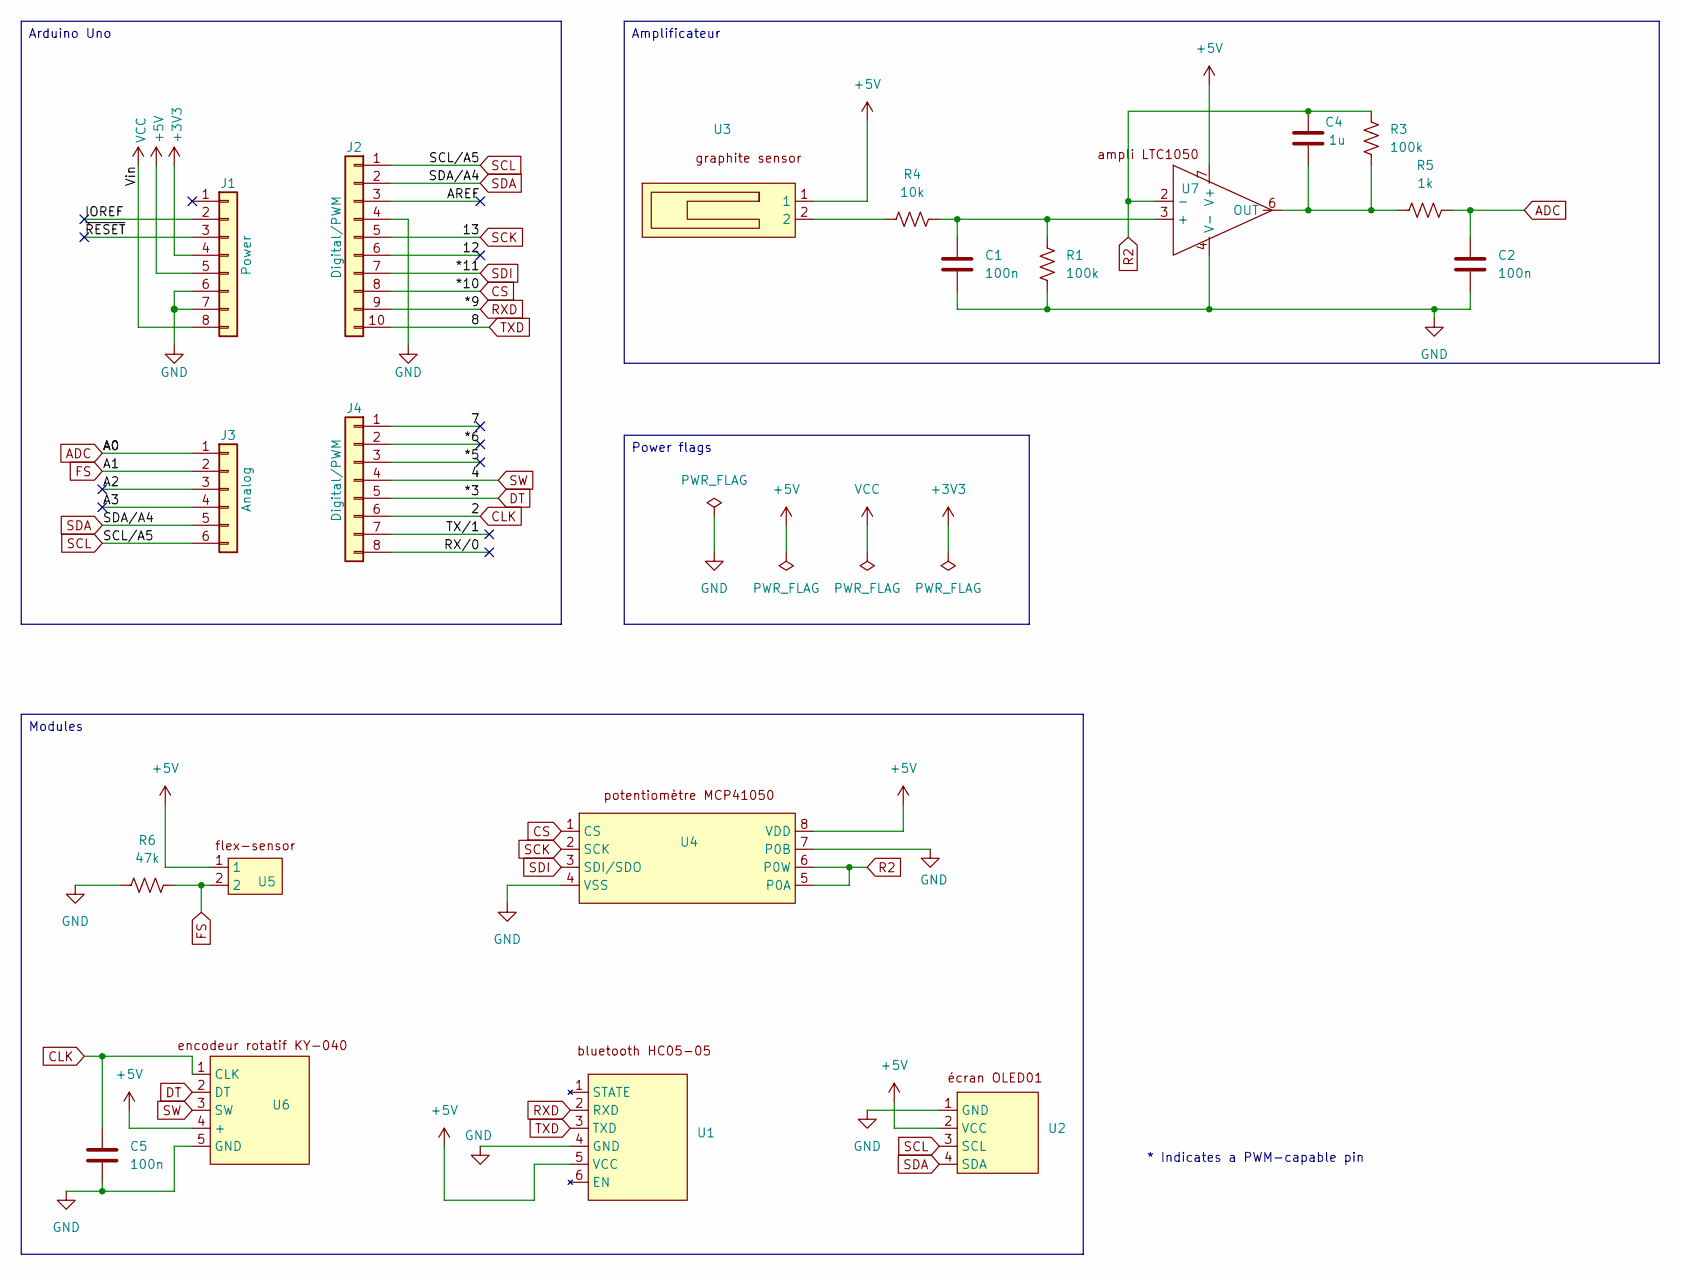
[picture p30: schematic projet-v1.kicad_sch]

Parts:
C1, C2, C5: 100n; C_Disc_D4.7mm_W2.5mm_P5.00mm
C4: 1u; C_Rect_L7.0mm_W4.5mm_P5.00mm
J1: Power; PinSocket_1x08_P2.54mm_Vertical
J2: Digital/PWM; PinSocket_1x10_P2.54mm_Vertical
J3: Analog; PinSocket_1x06_P2.54mm_Vertical
J4: Digital/PWM; PinSocket_1x08_P2.54mm_Vertical
R1, R3: 100k; R_Axial_DIN0207_L6.3mm_D2.5mm_P5.08mm_Vertical
R4: 10k; R_Axial_DIN0207_L6.3mm_D2.5mm_P5.08mm_Vertical
R5: 1k; R_Axial_DIN0207_L6.3mm_D2.5mm_P5.08mm_Vertical
R6: 47k; R_Axial_DIN0207_L6.3mm_D2.5mm_P5.08mm_Vertical
U1: HC05-05
U2: OLED01
U3: graphite-sensor
U4: MCP41050
U5: flex-sensor
U6: KY-040
U7: LTC1050

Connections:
+3V3: J1.4
+5V: J1.5, U1.5 (VCC), U2.2 (VCC), U3.1, U4.8 (VDD), U5.1, U6.4 (+), U7.7 (V+)
/7: J4.1
/12: J2.6
/*5: J4.3
/*6: J4.2
/A2: J3.3
/A3: J3.4
/AREF: J2.3
/IOREF: J1.2
/RX/0: J4.8
/TX/1: J4.7
/~RESET: J1.3
ADC: C2.1, J3.1, R5.2
CLK: C5.1, J4.6, U6.1 (CLK)
CS: J2.8, U4.1 (CS)
DT: J4.5, U6.2 (DT)
FS: J3.2, R6.2, U5.2
GND: C1.2, C2.2, C5.2, J1.6, J1.7, J2.4, R1.2, R6.1, U1.4 (GND), U2.1 (GND), U4.4 (VSS), U4.7 (P0B), U6.5 (GND), U7.4 (V-)
unnamed: R4.1, U3.2
unnamed: C1.1, R1.1, R4.2, U7.3 (+)
unnamed: C4.2, R3.2, R5.1, U7.6 (OUT)
R2: C4.1, R3.1, U4.5 (P0A), U4.6 (P0W), U7.2 (-)
RXD: J2.9, U1.2 (RXD)
SCK: J2.5, U4.2 (SCK)
SCL: J2.1, J3.6, U2.3 (SCL)
SDA: J2.2, J3.5, U2.4 (SDA)
SDI: J2.7, U4.3 (SDI/SDO)
SW: J4.4, U6.3 (SW)
TXD: J2.10, U1.3 (TXD)
VCC: J1.8

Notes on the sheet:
* Indicates a PWM-capable pin
Power flags
Amplificateur
Arduino Uno
Modules

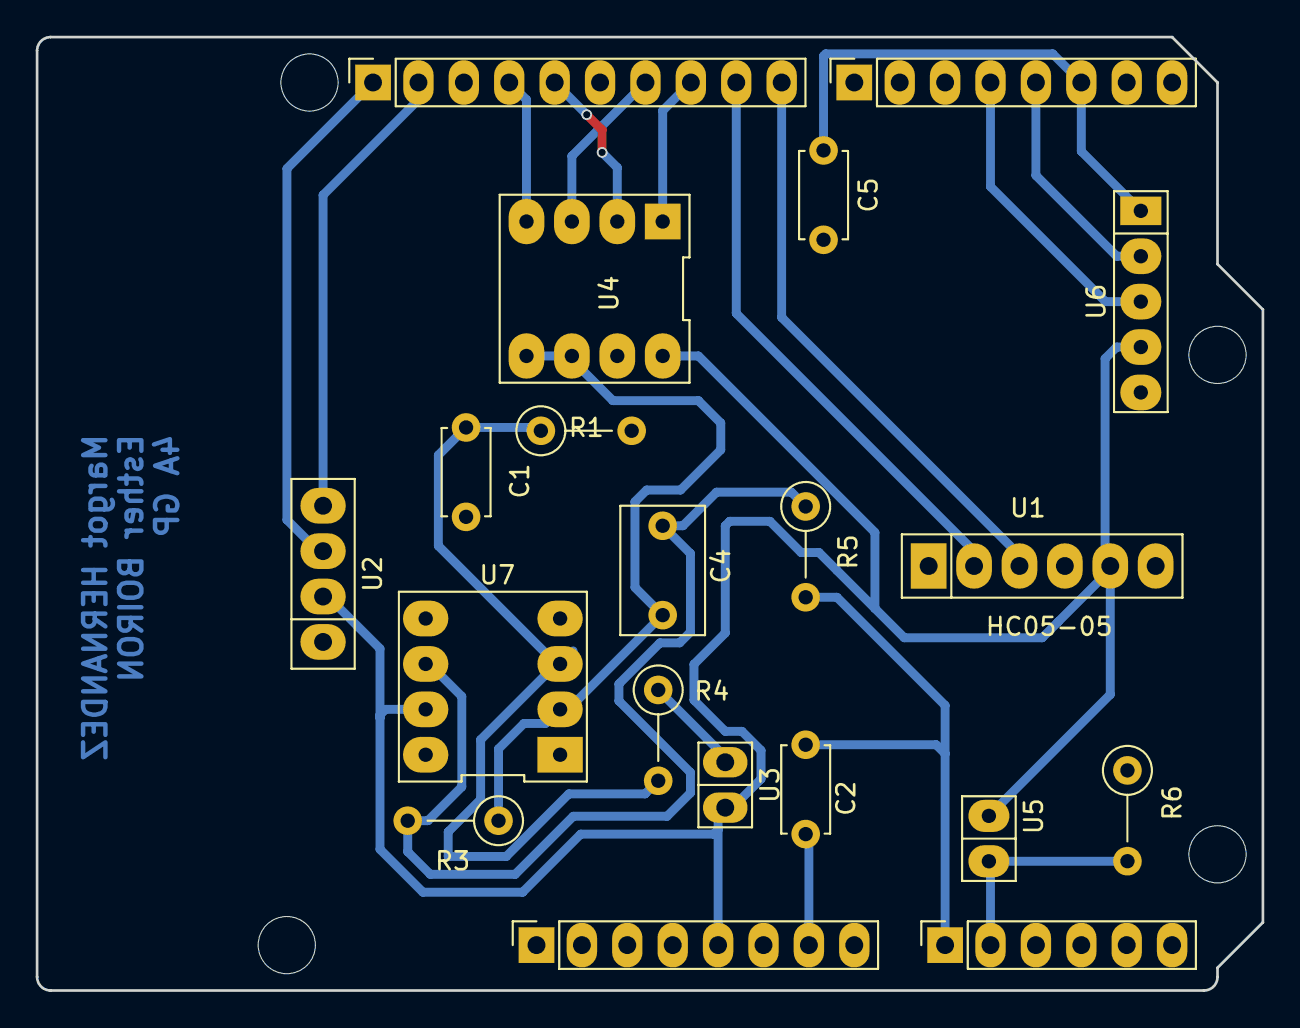
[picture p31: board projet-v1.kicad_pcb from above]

Board: 2 copper layers, 68.6 x 53.3 mm, 24 parts (0 on the bottom side), 18 nets.

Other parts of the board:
MH1, MH2, MH3, MH4: MountingHole_3.2mm

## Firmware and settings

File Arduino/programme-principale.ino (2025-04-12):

  // PROGRAMME ARDUINO Projet capteur 4A Génie Physique
  // Esther BOIRON
  // Margot HERNANDEZ

  ////////////////////  OLED
  #include <Adafruit_SSD1306.h>
  #include <Fonts/FreeMono9pt7b.h>
  #define largeur_ecran 128
  #define hauteur_ecran 64
  #define reset_ecran -1
  #define adresseI2C_OLED 0x3C
  Adafruit_SSD1306 ecran_OLED(largeur_ecran, hauteur_ecran, &Wire, reset_ecran);

  ////////////////////  BLUETOOTH
  #include <SoftwareSerial.h>
  #include <avr/pgmspace.h>         // Permet de stocker des données en mémoire flash (PROGMEM) au lieu de la RAM
  #include <SPI.h>
  #define rxPin 8
  #define txPin 9
  #define SERIAL
  SoftwareSerial mySerial(rxPin, txPin);
  int mode_app = 0;


  ////////////////////  CAPTEURS ET RESISTANCES
  const int pin_capteur_graphite = A0;
  const int pin_capteur_commercial = A1;
  const float R1 = 100000.0; 
  const float R3 = 100000.0; 
  const float R4 = 10000.0; 
  const float R6 = 33000.0; 
  const float Vcc = 5.0;
  float R2 = 515.0;             // Valeur correspondant à la position du potentiomètre digital

  //////////////////// POTENTIOMETRE DIGITAL
  const byte csPin           = 10;      // MCP42100 chip select pin
  const int  maxPositions    = 256;     // wiper can move from 0 to 255 = 256 positions
  const long rAB             = 50000;   // valeur à remplacer par la valeur réelle
  const byte rWiper          = 125;     // 125 ohms pot wiper resistance
  const byte pot0            = 0x11;    // pot0 addr // B 0001 0001
  const byte pot0Shutdown    = 0x21;    // pot0 shutdown // B 0010 0001 

  ////////////////////  ENCODEUR ROTATIF
  #define encoder0PinA 2
  #define encoder0PinB 3
  #define pin_bouton 4
  volatile int encoder0Pos = 0;
  const char menus[][20] PROGMEM = {"informations", "application", "capteur graphite", "capteur commercial"};    // liste des menus stockée en mémoire flash au lieu de la RAM
  const int nb_menus = sizeof(menus) / sizeof(menus[0]);
  int menu_index = 0, menu_etat = 0;
  long position_precedente = -999;

  ///////////////////// SET UP POTENTIOMETRE
  void setPotWiper(int addr, int pos) {
  pos = constrain(pos, 0, 255);            // limite les positions entre 0 et 255
  digitalWrite(csPin, LOW);                // enable chip select
  SPI.transfer(addr);                      
  SPI.transfer(pos);
  digitalWrite(csPin, HIGH);               // disable chip select
}
  void setup() {

      digitalWrite(csPin, HIGH);        // chip select default to de-selected
      pinMode(csPin, OUTPUT);           // configure chip select as output
      SPI.begin();
      pinMode(rxPin, INPUT);
      pinMode(txPin, OUTPUT);
      mySerial.begin(9600);
      Serial.begin(9600);

      if (!ecran_OLED.begin(SSD1306_SWITCHCAPVCC, adresseI2C_OLED)) 
      {
        while (1);  
      }
      ecran_OLED.setTextColor(SSD1306_WHITE, SSD1306_BLACK);
      ecran_OLED.clearDisplay();
      ecran_OLED.setTextSize(1);
      ecran_OLED.setCursor(0, 0);
      ecran_OLED.setFont(&FreeMono9pt7b);
      ecran_OLED.print(F("\n Projet\n capteur\n 4A GP"));
      ecran_OLED.display();
      delay(1000);
      ecran_OLED.setFont();
      afficher_menu();

      pinMode(encoder0PinA, INPUT_PULLUP);
      pinMode(encoder0PinB, INPUT_PULLUP);
      attachInterrupt(digitalPinToInterrupt(encoder0PinA), doEncoder, RISING);
      pinMode(pin_bouton, INPUT_PULLUP);
  }

  void loop() {

      setPotWiper(pot0,2);          // la position 2 est la position optimale d'après nos tests
      long position = encoder0Pos;
      if (menu_etat == 0) {        // Navigation dans le menu principal uniquement si menu_etat == 0 (0 = menu principal et 1 = sous-menu sélectionné)
      if (position != position_precedente) {
        if (position > position_precedente) {
          menu_index--;
        }
        if (position < position_precedente) {
          menu_index++;
        }

        if (menu_index < 0) menu_index = nb_menus - 1;
        if (menu_index >= nb_menus) menu_index = 0;

        afficher_menu();
        position_precedente = position;  
      }    
    }

      if (digitalRead(pin_bouton) == LOW) {
          delay(200);
          if (menu_etat == 0) {    // Si on est dans le menu principal, entrer dans un sous-menu
          menu_etat = 1;
          } else {                // Si on est déjà dans un sous-menu, revenir au menu principal
            menu_etat = 0;
              afficher_menu();
          }
          delay(200);
      }

      if (menu_etat == 1) 
      {
        afficher_sous_menu();
      }
      delay(100);
  }

  void doEncoder() {
      if (digitalRead(encoder0PinA) == HIGH && digitalRead(encoder0PinB) == HIGH) {
      encoder0Pos++;
    } else if (digitalRead(encoder0PinA) == HIGH && digitalRead(encoder0PinB) == LOW) {
      encoder0Pos--;
    }
  }

  void afficher_menu() {
      char buffer[20];
      strcpy_P(buffer, menus[menu_index]);
      ecran_OLED.clearDisplay();
      ecran_OLED.setCursor(0, 0);
      ecran_OLED.println(F("Menu:"));
      ecran_OLED.setCursor(0, 20);
      ecran_OLED.print(F("> "));
      ecran_OLED.println(buffer);
      ecran_OLED.display();
  }

  void afficher_sous_menu() {
      ecran_OLED.clearDisplay();
      ecran_OLED.setCursor(0, 0);
      
      if (menu_index == 0) {
          ecran_OLED.println("Menu informations :\n\n");
          ecran_OLED.println(" Projet capteur\n Esther BOIRON\n Margot HERNANDEZ\n 4A GP");

      } else if (menu_index == 1) {
            byte Vadc = analogRead(pin_capteur_graphite) / 4;
            byte ADCflex = analogRead(pin_capteur_commercial)/ 4;
            //Serial.print("ADCflex : ");
            //Serial.println(ADCflex);
            ecran_OLED.println("Menu application :\n");
            ecran_OLED.println(" RDV sur l'appli !\n");
            delay (400);
            Serial.println(mode_app);
            if (mySerial.available() > 0)
            {
              mode_app = mySerial.read();
            }

            if (mode_app == 1)
            {
                mySerial.write(Vadc);
            }
            else if (mode_app == 2)
            {
                mySerial.write(ADCflex);
            }

            while (mySerial.available()) {
              Serial.print((char) mySerial.read()) ;
            }

      } else if (menu_index == 2) {
              float Vadc = analogRead(pin_capteur_graphite) * Vcc / 1023.0;
              float Rgraphite = (Vcc/Vadc * (1+R3/R2)*R1-R1-R4)/pow(10,6);; 
              ecran_OLED.println("Menu capteur\n");
              ecran_OLED.println("graphite :\n");
              ecran_OLED.print(F(" Res: "));
              ecran_OLED.print(Rgraphite, 4);
              ecran_OLED.println(F(" MOhm"));

      } else if (menu_index == 3) {
          int ADCflex = analogRead(pin_capteur_commercial);
          float Vflex = ADCflex * Vcc / 1023.0;
          float Rflex = R6 * (Vcc / Vflex - 1.0);
          ecran_OLED.println("Menu capteur\n");
          ecran_OLED.println("commercial :\n");
            ecran_OLED.print(F(" Res: "));
            ecran_OLED.print(Rflex, 0);
            ecran_OLED.println(F(" Ohm"));
          } 

        ecran_OLED.display();
    }

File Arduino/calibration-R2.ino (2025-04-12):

/*
   MCP41050 Dual 50K 

   Ce programme réalise une recherche de maximum pour déterminer la valeur optimale de R2.
   Ensuite il récupère la valeur de tension en sortie de l'amplificateur et calcule la résistance du capteur de graphite.
*/

#include <SPI.h>

// initialize pins and constants
const byte csPin           = 10;      // MCP42100 chip select pin
const int  maxPositions    = 256;     // wiper can move from 0 to 255 = 256 positions
const long rAB             = 50000;   // valeur à remplacer par la valeur réelle
const byte rWiper          = 125;     // 125 ohms pot wiper resistance
const byte pot0            = 0x11;    // pot0 addr // B 0001 0001
const byte pot0Shutdown    = 0x21;    // pot0 shutdown // B 0010 0001 
const int adcPin           = A0 ;     // analog pin ADC is connected to 
const byte verifPin        = 7 ;      // digital pin used to check wether the research algorithm must be ran or not (choose a pin thatis not used by another device)

const float r1 = 100000 ;
const float r3 = 100000 ;
const float r4 = 10000 ;
const float Vcc = 5 ;
float r2 ;


void setPotWiper(int addr, int pos) {
  pos = constrain(pos, 0, 255);            // restrict possible positions from 0 to 255
  digitalWrite(csPin, LOW);                // enable chip select
  SPI.transfer(addr);                      
  SPI.transfer(pos);
  digitalWrite(csPin, HIGH);               // disable chip select
}

void setup() {
  Serial.begin(9600);
  Serial.println("MCP41100 Demo");
  
  digitalWrite(csPin, HIGH);        // chip select default to de-selected
  pinMode(csPin, OUTPUT);           // configure chip select as output
  SPI.begin();

  digitalWrite(verifPin, HIGH) ;    // initialize the pin to high
  pinMode(verifPin, OUTPUT) ;
  
}

void loop() {
    
    Serial.println("Recherche de maximum ");

    //initialize our variables
    float adc_max   = 0.0 ;
    int optimal_pos = 0 ;
  
   for (int i = 1; i < 256; i++) {
      setPotWiper(pot0, i);
      float adc = analogRead(adcPin) ;
      adc = adc*Vcc/1024;
      if ((adc > adc_max) && (adc < 5.0)) {
        optimal_pos = i ;
        adc_max = adc ;
      }
      // print pot resistance between wiper and B terminal
      long resistanceWB = ((rAB * i) / maxPositions ) + rWiper;
      Serial.print("Wiper position: ");
      Serial.println(i);
      Serial.print("Resistance wiper to B terminal: ");
      Serial.print(resistanceWB);
      Serial.println(" ohms");
      Serial.print ("Output voltage :") ;
      Serial.print (adc) ;
      Serial.println (" volts") ;
      delay(500);
    }

    Serial.print("The optimal position is :") ;
    Serial.println(optimal_pos) ;
    digitalWrite(verifPin, LOW) ;
    
    // move pot0 wiper to optimal position
    setPotWiper(pot0,optimal_pos);

    // compute r2 (resistance value corresponding to the optimal position)
    r2 =((rAB * optimal_pos) / maxPositions ) + rWiper ;
}

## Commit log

2025-04-12 MAJ README v6
    [projet1.kicad_pcb, projet1.kicad_sch]
2025-04-15 Update README.md 2
    Quelques modifs dans la partie "Simulation électronique sous LTSpice". Dans le texte de base tu dis que l'arduino ne peut pas mesurer des courants aussi faibles. Mais il me semble qu'il ne mesure pas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
2025-04-15 Update README.md 3
    juste des petites fautes d'orthopgraphe
2025-04-15 Update README.md 5
    Dans la partie Kicad : à la fin de chaque étape tu expliques l'étape suivante mais du coup dans l'étape suivante tu redis la même chose. Je sais pas si c'est voulu ou si c'est un souci de copié collé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
